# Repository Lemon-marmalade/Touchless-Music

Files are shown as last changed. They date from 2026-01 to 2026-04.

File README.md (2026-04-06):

# Touchless Music

Touchless Music is a hand-tracked musical instrument that leans fully into the ridiculous in the best possible way: part touchless otamatone, part solfege conductor, part computer vision experiment.

The core idea is split across two hands:

- One hand controls whether the instrument "sings" at all by making an open or closed sock-puppet shape.
- That same voice gets its pitch from distance to an ultrasonic sensor, creating a touchless slide instrument.
- The other hand performs solfege gestures (`Do Re Mi Fa So La Ti`) that trigger a second harmonizing voice.

While it's impractical, overengineered, and deeply committed to making music in a way no one asked for, this has been a fun side project, and that's sort of the whole essence I was going for :)

## What This Repo Contains

This repository includes the computer-vision pipeline, trained models, Arduino sketches, datasets, and hardware files used to build the instrument.

### Python / ML

- `predict.py`: main runtime script. Detects both hands with MediaPipe, classifies gestures with PyTorch, and sends the results to Arduino over serial.
- `collect_r.py`: collects right-hand training data for `OPEN` vs `CLOSED`.
- `collect_l.py`: collects left-hand training data for `DO RE MI FA SO LA TI`.
- `train.py`: trains a feedforward classifier from CSV landmark data.
- `RH_predict.py`: tests the right-hand gesture model by itself.
- `LH_predict.py`: tests the left-hand gesture model by itself.
- `test.py`: visual hand-tracking sanity check with MediaPipe landmarks only.

### Models and data

- `hand_landmarker.task`: MediaPipe hand landmark model asset.
- `RH_dataset.csv`: right-hand training samples.
- `LH_dataset2.csv`: left-hand training samples.
- `RH_model.pt`: trained right-hand classifier.
- `LH_model2.pt`: trained left-hand classifier.
- `hands_dataset(test).csv`: additional dataset artifact.

### Arduino

- `Touchless_Music_Arduino_Code/Touchless_Music_Arduino_Code.ino`: full two-voice system. One buzzer is pitch-controlled by ultrasonic distance, the second buzzer is driven by solfege gesture labels from the left hand.
- `Touchless_Otamatone_original/Touchless_Otamatone_original.ino`: earliest single-voice touchless otamatone prototype.
- `Touchless_Otamatone_button_control/Touchless_Otamatone_button_control.ino`: intermediate version that only plays when a separate speak/button signal is active.

### Hardware and reference files

- `CAD/`: printable enclosure and slider parts.
- `Wiring/`: build photos for the buzzer-only and push-button versions.

## How It Works

At runtime, the webcam feed is processed with MediaPipe Hands. For each detected hand, the 21 landmark positions are flattened into 63 values (`x, y, z` for every joint) and passed into a small neural network.

The repo currently uses two separate classifiers:

- Right hand: `OPEN` or `CLOSED`
- Left hand: `DO RE MI FA SO LA TI`

`predict.py` sends both predictions to Arduino as a serial message:

```text
<right-hand-label> <left-hand-label>
```

The Arduino sketch then does two things:

- If the right hand is `OPEN`, it reads the ultrasonic sensor and maps hand distance to a chromatic pitch.
- If the left hand is recognized as a solfege sign, it plays a harmonizing note on a second buzzer.

## Setup

### 1. Create a Python environment

```bash
python3 -m venv .venv
source .venv/bin/activate
pip install -r requirements.txt
```

### 2. Connect hardware

The full version expects:

- a webcam
- an Arduino-compatible board
- an ultrasonic distance sensor
- two buzzers/speakers

Wiring reference photos are in `Wiring/`, and the full sketch lives in `Touchless_Music_Arduino_Code/`.

### 3. Check Arduino dependencies

The Arduino sketches include `pitches.h`, but that header is not currently committed in this repo. You will need to add it to the Arduino sketch folder or your Arduino project before uploading.

### 4. Set the serial port

`predict.py` currently hard-codes:

```python
SERIAL_PORT = "/dev/cu.usbmodem101"
```

Change that value to match your machine before running the full system.

## Running the Project

### Quick webcam sanity check

```bash
python test.py
```

This only verifies MediaPipe hand tracking.

### Test each classifier independently

```bash
python RH_predict.py
python LH_predict.py
```

### Run the full instrument

1. Upload `Touchless_Music_Arduino_Code/Touchless_Music_Arduino_Code.ino` to the board.
2. Confirm the serial port in `predict.py`.
3. Run:

```bash
python predict.py
```

Press `q` to quit the OpenCV window.

## Collecting More Training Data

To record additional gesture samples:

```bash
python collect_r.py
python collect_l.py
```

Controls:

- `collect_r.py`: `o` = open, `c` = closed, `q` = quit
- `collect_l.py`: `d r m f s l t` = `Do Re Mi Fa So La Ti`, `q` = quit

Each captured frame stores MediaPipe landmarks plus a label into the corresponding CSV file.

## Retraining

The current `train.py` is configured for the left-hand 7-class model:

```bash
python train.py
```

If you want to retrain the right-hand model, update the dataset path and output class count in `train.py` first.

## Repo Notes

- The models were trained on mirrored webcam input, so several scripts flip the frame before inference.
- In `predict.py`, MediaPipe handedness is intentionally interpreted in reverse because the display is mirrored.
- The current setup is tuned for local experimentation rather than polished deployment.

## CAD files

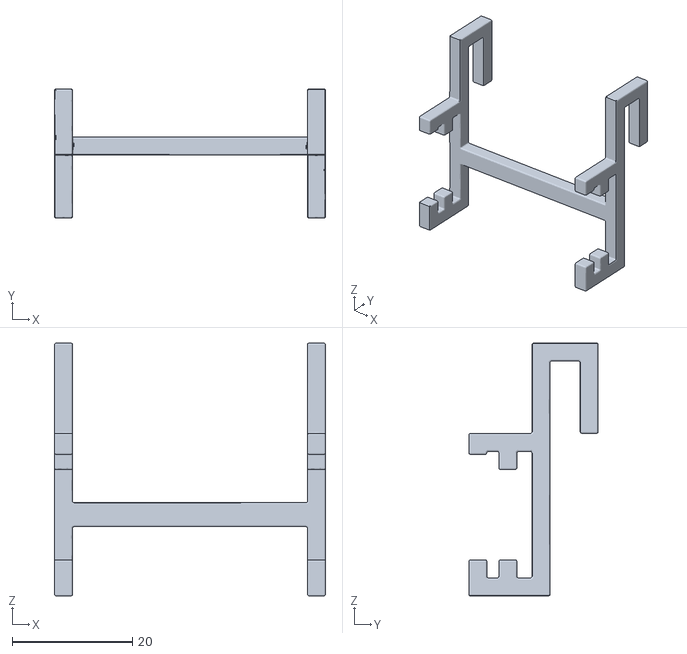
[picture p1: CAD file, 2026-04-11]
CAD/Sensor holder v5.stl
45.0 x 21.5 x 42.0

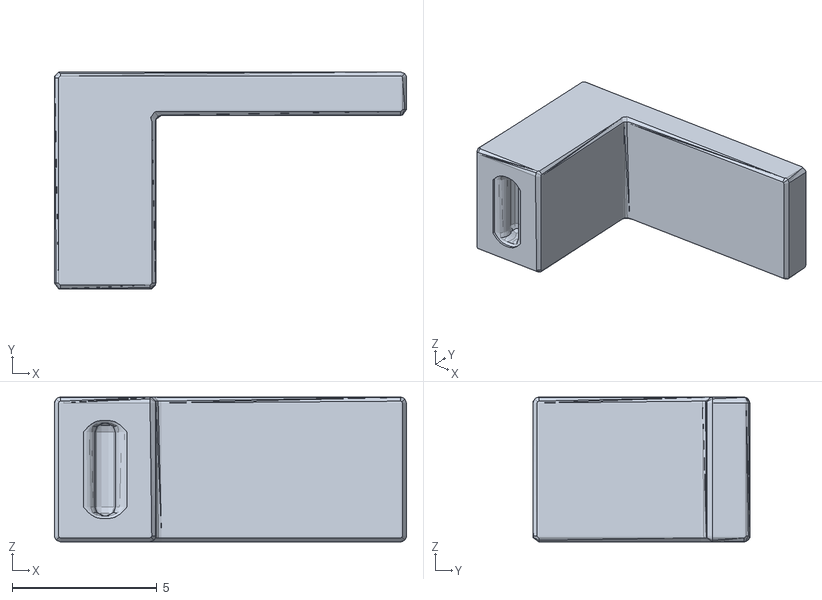
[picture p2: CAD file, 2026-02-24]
CAD/Slider v2.stl
12.2 x 7.50 x 5.00

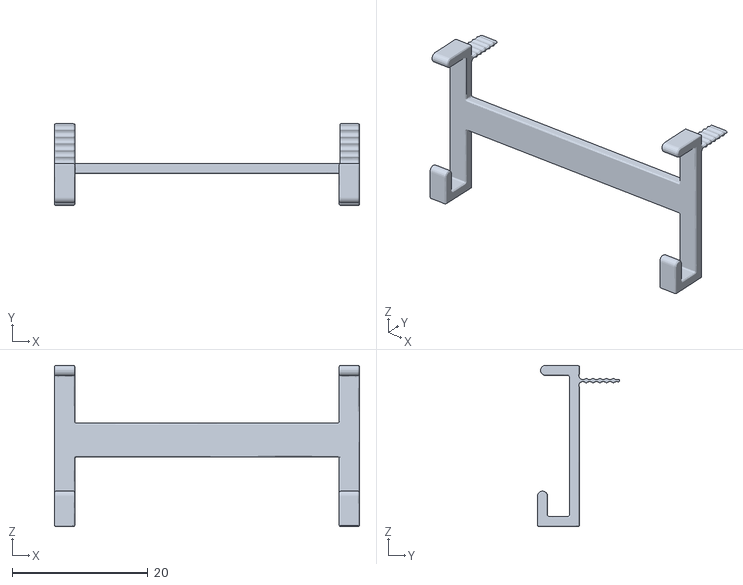
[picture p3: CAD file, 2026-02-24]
CAD/Base v3.stl
45.0 x 12.1 x 23.8

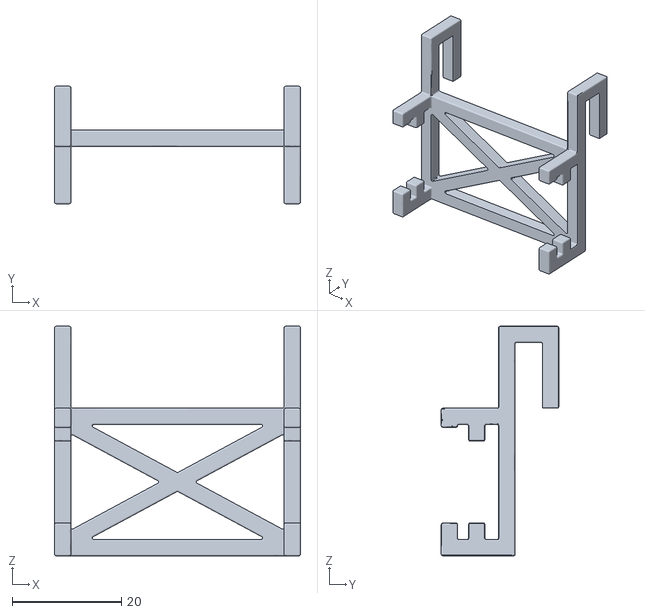
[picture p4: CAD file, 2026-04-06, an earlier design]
CAD/sensor holder v4.stl
45.0 x 21.5 x 42.0

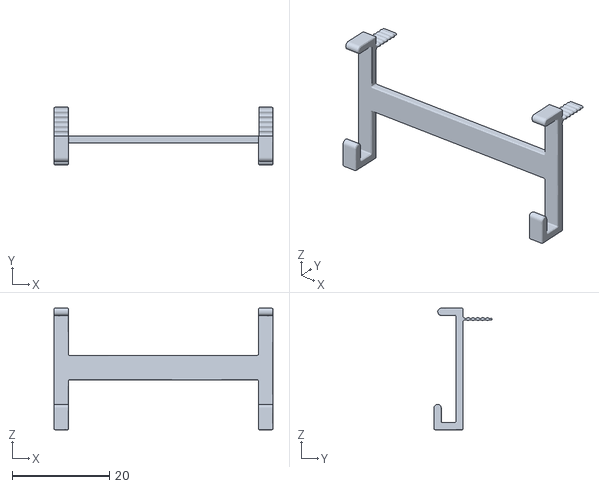
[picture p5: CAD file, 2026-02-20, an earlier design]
CAD/Base_v2_1.stl
45.0 x 11.9 x 25.0

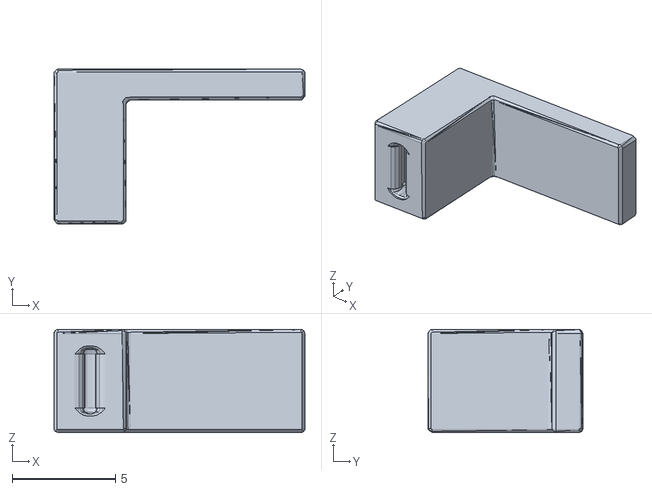
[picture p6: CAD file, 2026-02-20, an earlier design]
CAD/Slider.stl
12.2 x 7.50 x 5.00

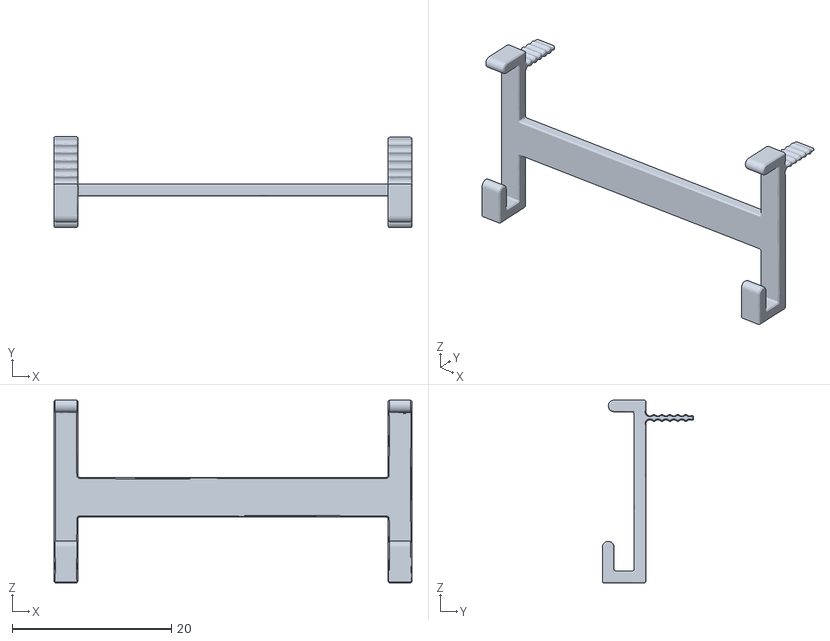
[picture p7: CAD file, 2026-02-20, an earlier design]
CAD/Base_v1.stl
45.0 x 11.5 x 23.0

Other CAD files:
CAD/Base_v2.stl

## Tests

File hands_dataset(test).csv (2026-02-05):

0.36649131774902344 | 0.7388118505477905 | 3.986313856785273e-07 | 0.42101773619651794 | 0.6964208483695984 | -0.021848920732736588 | 0.4653656780719757 | 0.6096248626708984 | -0.026212740689516068 | 0.49249863624572754 | 0.5333418846130371 | -0.029215555638074875 | 0.5125181674957275 | 0.4773861765861511 | -0.0320628397166729 | 0.4307088255882263 | 0.50087571144104 | -0.006406266707926989 | 0.45033538341522217 | 0.4073273539543152 | -0.018171239644289017 | 0.4608370065689087 | 0.3484766483306885 | -0.029804900288581848 | 0.4697624444961548 | 0.29866689443588257 | -0.03839484229683876 | 0.40105947852134705 | 0.4876069128513336 | -0.006056841928511858 | 0.41666844487190247 | 0.3820856809616089 | -0.01696881465613842 | 0.4282374083995819 | 0.31021589040756226 | -0.029738150537014008 | 0.438123494386673 | 0.25188788771629333 | -0.039163779467344284 | 0.3698679804801941 | 0.49359121918678284 | -0.009733680635690689 | 0.37656325101852417 | 0.38673698902130127 | -0.02342778816819191 | 0.38476064801216125 | 0.3191313147544861 | -0.03621859475970268 | 0.3937452435493469 | 0.2641853988170624 | -0.04464876279234886 | 0.3362112045288086 | 0.5134068727493286 | -0.0156386885792017 |
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

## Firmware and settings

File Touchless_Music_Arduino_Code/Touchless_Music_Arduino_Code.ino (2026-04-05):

#include "pitches.h"

#define BUZZER1 9   // Timer1 OC1A (D9)
#define ECHO 11
#define TRIG 10
#define BUZZER2 3   // Timer2 OC2B (D3)

int scale1[] = {NOTE_C5, NOTE_CS5, NOTE_D5, NOTE_DS5, NOTE_E5, NOTE_F5, NOTE_FS5, NOTE_G5, NOTE_GS5, NOTE_A5, NOTE_AS5, NOTE_B5, NOTE_C6};
int scale2[] = {NOTE_C4, NOTE_D4, NOTE_E4, NOTE_F4, NOTE_G4, NOTE_A4, NOTE_B4};

// Timer1 prescaler = 8: OCR1A = 16000000 / (2 * 8 * freq) - 1
const uint16_t scale1_ocr[13] = 
{
  1912, 1805, 1703, 1607, 1517, 1432, 1351,
  1275, 1203, 1135, 1071, 1011, 955
};

// Timer2 prescaler = 256: OCR2A = OCR2B = 16000000 / (2 * 256 * freq) - 1
const uint8_t scale2_ocr[7] = 
{
  119,  // C4  261.63 Hz
  106,  // D4  293.66 Hz
  94,   // E4  329.63 Hz
  89,   // F4  349.23 Hz
  79,   // G4  392.00 Hz
  70,   // A4  440.00 Hz
  63    // B4  493.88 Hz
};

void setupTimers() 
{
  // Timer1: * need full register writes instead of bit fiddling to account for bits changed by Arduino bootloader
  TCCR1A = 0;
  TCCR1B = 0;
  TCCR1A = (1 << COM1A0); // toggle OC1A, disconnected until note starts
  TCCR1B = (1 << WGM12) | (1 << CS11); // CTC, prescaler 8

  // Timer2: full register writes
  TCCR2A = 0;
  TCCR2B = 0;
  TCCR2A = (1 << WGM21); // CTC, OC2B disconnected until note starts
  TCCR2B = (1 << CS22) | (1 << CS21); // prescaler 256
}

void startBuzzer1_idx(int noteIdx) 
{
  if (noteIdx < 0 || noteIdx >= 13) 
  {
    TCCR1A = (1 << COM1A0);  // keep toggle mode but disconnected? 
    // actually just clear COM1A0 to disconnect
    TCCR1A = 0;
    digitalWrite(BUZZER1, LOW);
    return;
  }
  OCR1A  = scale1_ocr[noteIdx];
  TCCR1A = (1 << COM1A0);   // connect OC1A toggle
}

void stopBuzzer1() 
{
  TCCR1A = 0;               // disconnect OC1A
  digitalWrite(BUZZER1, LOW);
}

void startBuzzer2_idx(int noteIdx) 
{
  if (noteIdx < 0 || noteIdx >= 7) 
  {
    TCCR2A = (1 << WGM21);  // keep CTC but disconnect OC2B
    digitalWrite(BUZZER2, LOW);
    return;
  }
  TCNT2  = 0;
  OCR2A  = scale2_ocr[noteIdx];
  OCR2B  = scale2_ocr[noteIdx];
  TCCR2A = (1 << COM2B0) | (1 << WGM21);  // connect OC2B toggle, CTC
}

void stopBuzzer2() 
{
  TCCR2A = (1 << WGM21);   // keep CTC but disconnect OC2B
  digitalWrite(BUZZER2, LOW);
}

int idx = -1, lastIdx = -1, lastL = -2; // lastL=-2 so first update always fires (-2 for never set, -1 explicitly stopped)

void setup() 
{
  Serial.begin(115200);
  pinMode(ECHO, INPUT);
  pinMode(TRIG, OUTPUT);
  pinMode(BUZZER1, OUTPUT);
  pinMode(BUZZER2, OUTPUT);

  digitalWrite(BUZZER1, LOW);
  digitalWrite(BUZZER2, LOW);

  setupTimers();
}

void loop() 
{
  int newR = -1, newL = -1;
  if (Serial.available() >= 1) 
  {
    newR = Serial.parseFloat();
    newL = Serial.parseFloat();
  }

  // -- Right Hand (ultrasonic) --
  if (newR == 0) {
    digitalWrite(TRIG, LOW);
    delayMicroseconds(2);
    digitalWrite(TRIG, HIGH);
    delayMicroseconds(10);
    digitalWrite(TRIG, LOW);

    long echo = pulseIn(ECHO, HIGH, 60000);

    if (echo == 0) {
      return; // no echo, keep last note playing
    } 
    else 
    {
      float distance = echo * 0.034 / 2.0;
      distance = constrain(distance, 0, 25);
      idx = map(distance, 8, 25, 0, 12);

      if (idx != lastIdx) 
      {
        startBuzzer1_idx(idx);
        lastIdx = idx;
      }
    }
  } 
  else 
  {
    stopBuzzer1();
    lastIdx = -1;
  }

  // -- Left Hand (gesture -> scale2) --
  if (newL >= 0 && newL <= 6)
  {
    if (newL != lastL)
    {
      startBuzzer2_idx(newL);
      lastL = newL;
    }
  }
  else
  {
    if (lastL != -1) // only stop if it was playing
    {
      stopBuzzer2();
      lastL = -1;
    }
  }
}

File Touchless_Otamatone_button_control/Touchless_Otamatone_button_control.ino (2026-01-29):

#include "pitches.h"

#define ECHO 11
#define TRIG 10
#define SPEAK 9
#define BUZZER 8

// chromatic scale
int scale[] = {NOTE_C5, NOTE_CS5, NOTE_D5, NOTE_DS5, NOTE_E5, NOTE_F5, NOTE_FS5, NOTE_G5, NOTE_GS5, NOTE_A5, NOTE_AS5, NOTE_B5, NOTE_C6};

int idx, lastIdx;

void setup() {
  //Serial.begin(9600); // for debugging
  pinMode(ECHO, INPUT);
  pinMode(TRIG, OUTPUT);
  pinMode(SPEAK, INPUT);
  pinMode(BUZZER, OUTPUT);
}

void loop() {
  if (digitalRead(SPEAK)==HIGH) // only make sound when speak signal is high
  {
    // Send ultrasonic pulse
    digitalWrite(TRIG, LOW);
    delayMicroseconds(2);
    digitalWrite(TRIG, HIGH); // 10 us pulse
    delayMicroseconds(10);
    digitalWrite(TRIG, LOW);

    long echo = pulseIn(ECHO, HIGH, 60000); // timeout: wait 60ms (best sounding). if no echo, do nothing
    if (echo == 0) {
      // no echo keep previous note, don't retrigger
      tone(BUZZER, scale[lastIdx]);
      return;
    }
    float distance = echo * 0.034 / 2;   // cm

    // clamp distance to 0–25 cm range
    distance = constrain(distance, 0, 25);

    // divide into 8 buckets (for the 13 notes) across 1–25 cm 
    // (lower bound is higher as an offset of sensor imperfections)
    idx = map(distance, 2, 25, 0, 12);

    //idx = constrain(idx, 0, 12); // redundant...?

    // only change tone when distance changes
    if (idx != lastIdx) {
      tone(BUZZER, scale[idx]); 
      lastIdx = idx;
    }
  }
  else
  {
    noTone(BUZZER);
  }
}

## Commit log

2026-01-29 Add files via upload
    Currently, this arduino code only encompasses the scale with an ultrasonic sensor (ie. no otamatone speaker function yet).
2026-01-30 Add pictures of Arduino setup for reference
2026-02-05 add sample count tracking and dynamic appending to datacollect
    [hands_dataset(test).csv]
2026-02-08 mirror datacollector displays, try compiling dataset for RH
    [RH_dataset.csv]
2026-02-09 add LH_dataset and tentative model and trainer
    [LH_dataset.csv]
2026-02-11 add print statements to help track progress
2026-02-20 add sensor holder files
    [Base_v1.stl, Base_v2.stl, Slider.stl]
2026-02-20 update lh data and model for better performance, update cad base
    [Base_v2_1.stl, LH_dataset2.csv]
2026-02-20 fix predict.py mirroring and model gap, change to using LH_model2
    [predict.py]
2026-02-22 remove old files
    [LH_dataset.csv]
2026-02-23 add portion to connect to arduino serial
2026-02-24 update cad, requirements, arduino code, etc.
    [Base v3.stl, Slider v2.stl]
2026-03-05 modify Arduino code to support both buzzers using timer
    [Touchless_Music_Arduino_Code.ino, predict.py]
2026-04-05 change to timer-based arduino sketch
2026-04-05 smooth left hand notes by selective update, and change ultrasonic range clamp
2026-04-06 add new cad design
    [sensor holder v4.stl]
2026-04-11 add final holder stl
    [Sensor holder v5.stl]
2026-04-14 add final wiring picture with 3d printed mount
